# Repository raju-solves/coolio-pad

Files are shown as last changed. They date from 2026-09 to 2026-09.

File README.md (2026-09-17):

## live ysws finale

### coolio pad

A compact custom hackpad with 15 mechanical keys and a rotary encoder..
designed for quick shortcuts and smooth control. 
It also includes two LED lights 
The clean layout makes it easy to use for everyday tasks.

Each key is programmed to Do a specific shortcut command on the computer.
The rotary encoder can be used for actions like adjusting volume.
The LEDs show status or activity








## Bill of Materials (BOM)

| Name | Description | Quantity | Price (USD) | Link |
|---|---|---:|---:|---|
| XIAO RP2040 | Seeed Studio XIAO RP2040 microcontroller | 1 | 21$ | [Amazon.in](https://www.amazon.in/dp/B0DRNTQ338) |
| MX Mechanical Switches | MX-compatible mechanical keyboard switches | 15 | ~$3.96 / pack | [Amazon.in](https://www.amazon.in/dp/B0FPR2ML31) |
| 1N4148 Diodes | General-purpose switching diodes for keyboard matrix | 16 | $2.80 | [Amazon.in](https://www.amazon.in/s?k=1N4148+diode+100+pcs) |
| Rotary Encoder | EC11 rotary encoder with push-button switch | 1 | ~$1.80–$2.81 | [Amazon.in](https://www.amazon.in/s?k=EC11+rotary+encoder+5+pin+with+switch) |
| Screws | M2 / M2.5 screws for assembling the case | 4 | $3.95 | [Amazon.in](https://www.amazon.in/s?k=M2+M2.5+screws) |

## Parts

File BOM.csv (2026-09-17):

Name | Description | Quantity | Price (USD) | Link
XIAO RP2040 | Seeed Studio XIAO RP2040 microcontroller | 1 | Check listing | https://www.amazon.in/dp/B0DRNTQ338
MX Mechanical Switches | MX-compatible mechanical keyboard switches | 15 | ~3.96 / pack | https://www.amazon.in/dp/B0FPR2ML31
1N4148 Diodes | General-purpose switching diodes for keyboard matrix | 16 | Check listing | https://www.amazon.in/s?k=1N4148+diode+100+pcs
Rotary Encoder | EC11 rotary encoder with push-button switch | 1 | ~1.80-2.81 | https://www.amazon.in/s?k=EC11+rotary+encoder+5+pin+with+switch
Screws | M2 / M2.5 screws for assembling the case | 4 | Check listing | https://www.amazon.in/s?k=M2+M2.5+screws

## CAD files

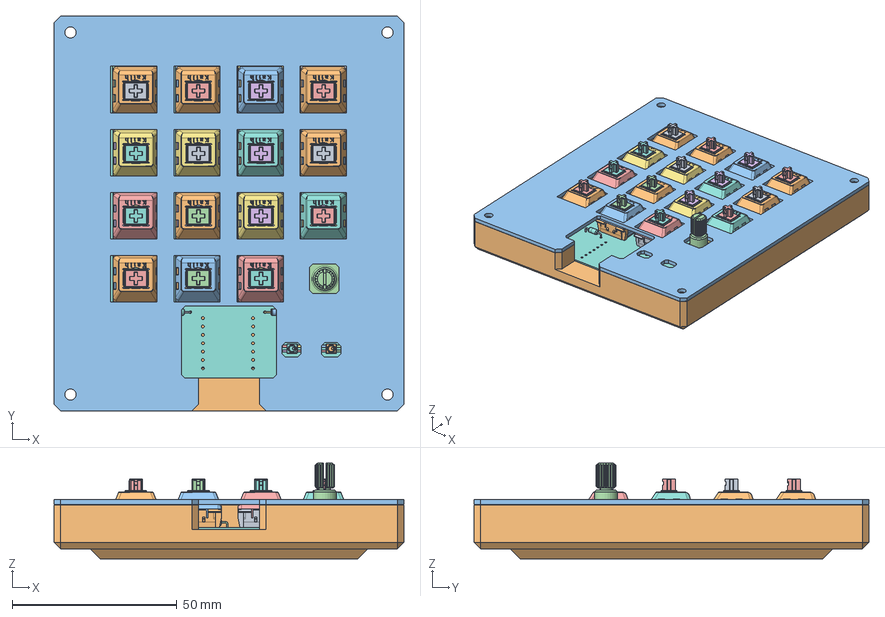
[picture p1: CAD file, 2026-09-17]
CAD/SOURCE FILE ASSEMBLY.FCStd
106.3 x 120.0 x 29.1 mm
LED_SK6812MINI-E
LED_SK6812MINI-E001
D_DO-35_SOD27_P7.62mm_Horizontal
LED_SK6812MINI-E002
D_DO-35_SOD27_P7.62mm_Horizontal001
D_DO-35_SOD27_P7.62mm_Horizontal002
D_DO-35_SOD27_P7.62mm_Horizontal003
D_DO-35_SOD27_P7.62mm_Horizontal004
D_DO-35_SOD27_P7.62mm_Horizontal005
D_DO-35_SOD27_P7.62mm_Horizontal006
D_DO-35_SOD27_P7.62mm_Horizontal007
D_DO-35_SOD27_P7.62mm_Horizontal008
D_DO-35_SOD27_P7.62mm_Horizontal009
D_DO-35_SOD27_P7.62mm_Horizontal010
D_DO-35_SOD27_P7.62mm_Horizontal011
D_DO-35_SOD27_P7.62mm_Horizontal012
D_DO-35_SOD27_P7.62mm_Horizontal013
LED_SK6812MINI-E003
Hackpad 1.1.1
Hackpad 1.1.002
Hackpad 1.1.003
Hackpad 1.1.004
Hackpad 1.1.005
D_DO-35_SOD27_P7.62mm_Horizontal014
D_DO-35_SOD27_P7.62mm_Horizontal015
D_DO-35_SOD27_P7.62mm_Horizontal016
D_DO-35_SOD27_P7.62mm_Horizontal017
D_DO-35_SOD27_P7.62mm_Horizontal018
LED_SK6812MINI-E004
D_DO-35_SOD27_P7.62mm_Horizontal019
LED_SK6812MINI-E005
D_DO-35_SOD27_P7.62mm_Horizontal020
D_DO-35_SOD27_P7.62mm_Horizontal021
D_DO-35_SOD27_P7.62mm_Horizontal022
Hackpad 1.1.006
Hackpad 1.1.007
Hackpad 1.1.008
Hackpad 1.1.009
Hackpad 1.1.010
Hackpad 1.1.011
Hackpad 1.1.012
Hackpad 1.1.013
Hackpad 1.1.014
Hackpad 1.1.015
Hackpad 1.1.016
Hackpad 1.1.017
Hackpad 1.1.018
Hackpad 1.1.019
Hackpad 1.1.020
Hackpad 1.1.021
Hackpad 1.1.022
Hackpad 1.1.023
Hackpad 1.1.024
Hackpad 1.1.025
D_DO-35_SOD27_P7.62mm_Horizontal023
LED_SK6812MINI-E006
LED_SK6812MINI-E007
LED_SK6812MINI-E008
D_DO-35_SOD27_P7.62mm_Horizontal024
D_DO-35_SOD27_P7.62mm_Horizontal025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

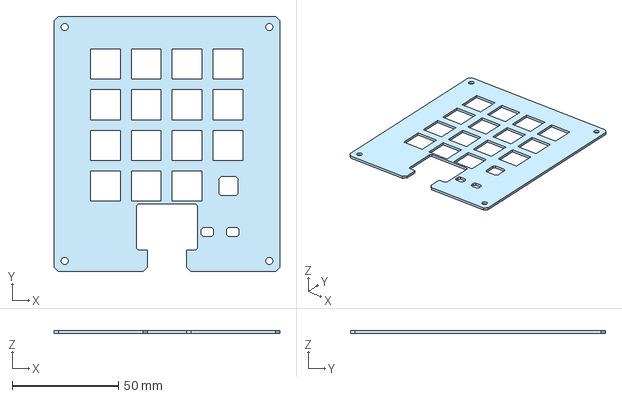
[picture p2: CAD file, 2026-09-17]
CAD/coolio top.step
106.3 x 120.0 x 1.50 mm

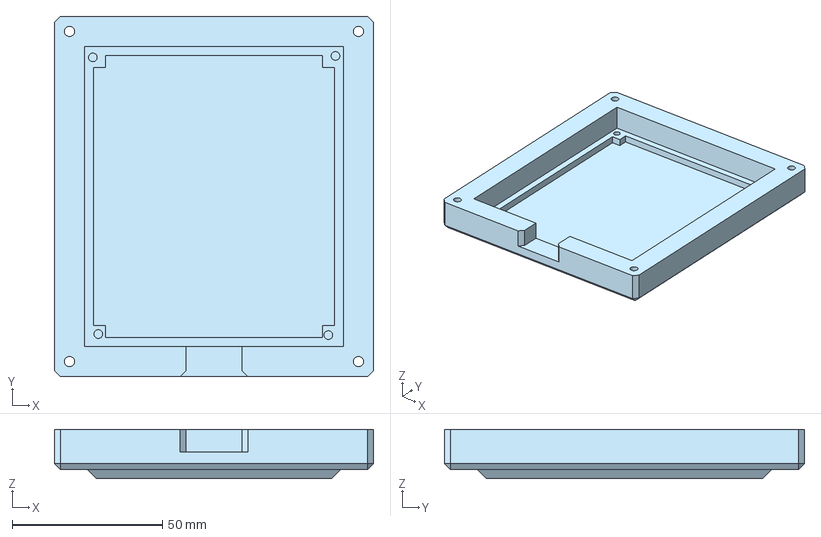
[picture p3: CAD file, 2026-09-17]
CAD/coolio bottom.step
106.3 x 120.0 x 16.4 mm

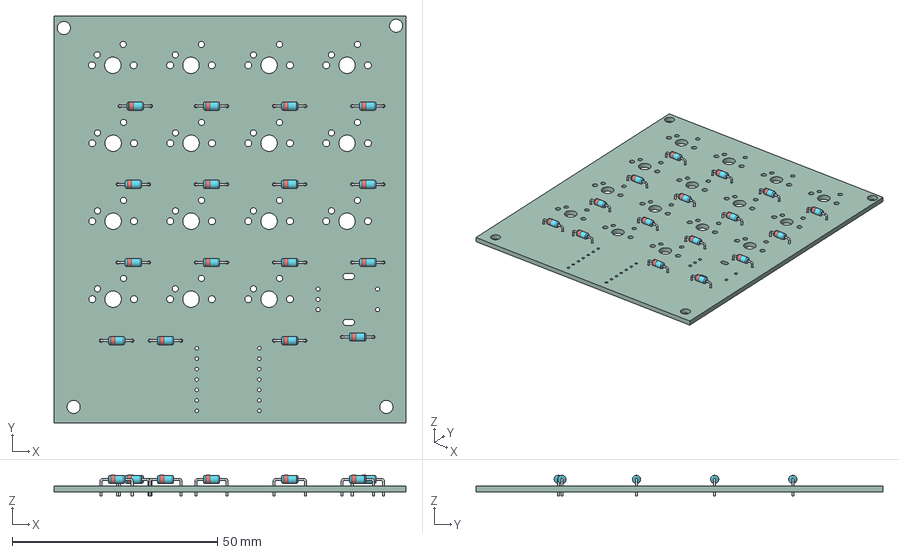
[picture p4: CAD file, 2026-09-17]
CAD/coolio pcb.step
85.7 x 99.2 x 5.01 mm
D_DO-35_SOD27_P7.62mm_Horizontal x 16
mini keyboard_PCB

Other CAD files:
CAD/ASSEMBLY.step

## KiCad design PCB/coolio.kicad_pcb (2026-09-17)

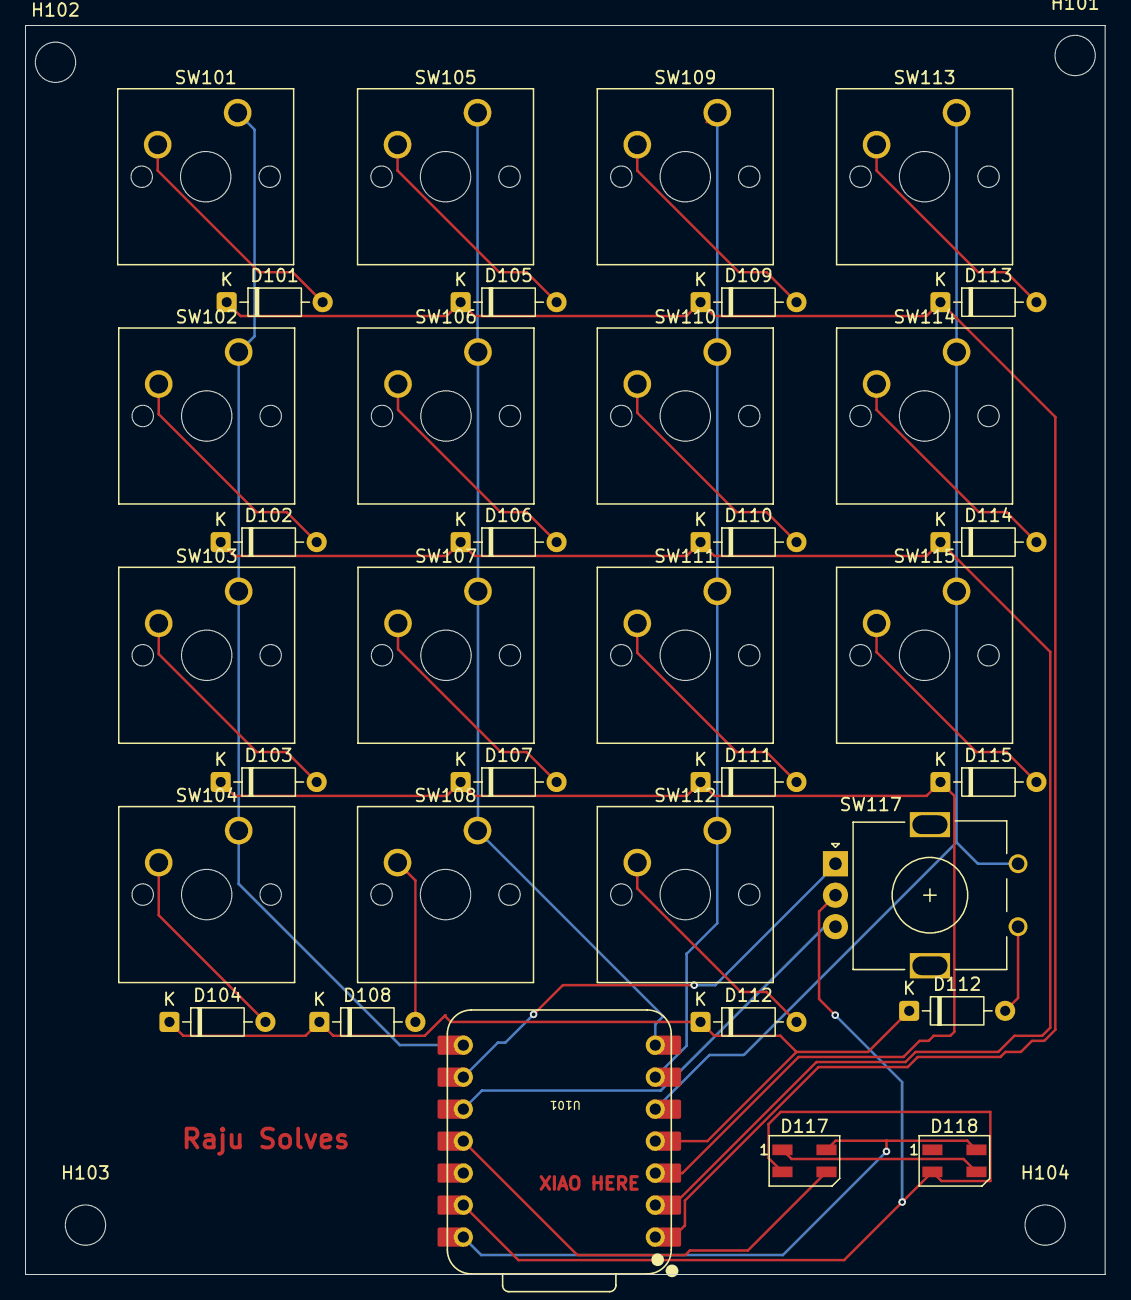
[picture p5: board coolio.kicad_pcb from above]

Board: 2 copper layers, 85.7 x 99.2 mm, 39 parts (0 on the bottom side), 29 nets.

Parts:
D101, D102, D103, D104, D105, D106, D107, D108, D109, D110, D111, D112, D112#2, D113, D114, D115: 1N4148; D_DO-35_SOD27_P7.62mm_Horizontal
D117, D118: SK6812MINI; LED_SK6812MINI_PLCC4_3.5x3.5mm_P1.75mm
H101, H102, H103, H104: MountingHole; MountingHole_3.2mm_M3
SW101, SW102, SW103, SW104, SW105, SW106, SW107, SW108, SW109, SW110, SW111, SW112, SW113, SW114, SW115: SW_Push; SW_Cherry_MX_1.00u_PCB
SW117: RotaryEncoder; RotaryEncoder_Alps_EC11E_Vertical_H20mm
U101: XIAO-RP2040-DIP

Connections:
+5V: D117.4 (VDD), D118.4 (VDD), U101.14 (VBUS)
GND: D117.2 (VSS), D118.2 (VSS), SW117.C, U101.13 (GND)
unnamed: D101.2 (A), SW101.2
unnamed: D101.1 (K), D105.1 (K), D109.1 (K), D113.1 (K), U101.1 (GPIO26/ADC0/A0)
unnamed: D102.2 (A), SW102.2
unnamed: D102.1 (K), D106.1 (K), D110.1 (K), D114.1 (K), U101.2 (GPIO27/ADC1/A1)
unnamed: D103.2 (A), SW103.2
unnamed: D103.1 (K), D107.1 (K), D111.1 (K), D115.1 (K), U101.3 (GPIO28/ADC2/A2)
unnamed: D104.2 (A), SW104.2
unnamed: D104.1 (K), D108.1 (K), D112.1 (K), D112#2.1 (K), U101.4 (GPIO29/ADC3/A3)
unnamed: D105.2 (A), SW105.2
unnamed: D106.2 (A), SW106.2
unnamed: D107.2 (A), SW107.2
unnamed: D108.2 (A), SW108.2
unnamed: D109.2 (A), SW109.2
unnamed: D110.2 (A), SW110.2
unnamed: D111.2 (A), SW111.2
unnamed: D112#2.2 (A), SW112.2
unnamed: D113.2 (A), SW113.2
unnamed: D114.2 (A), SW114.2
unnamed: D115.2 (A), SW115.2
unnamed: D117.3 (DIN), U101.11 (GPIO3/MOSI)
unnamed: D117.1 (DOUT), D118.3 (DIN)
unnamed: SW105.1, SW106.1, SW107.1, SW108.1, U101.7 (GPIO0/TX)
unnamed: SW101.1, SW102.1, SW103.1, SW104.1, U101.8 (GPIO1/RX)
unnamed: SW117.A, U101.9 (GPIO2/SCK)
unnamed: SW117.B, U101.10 (GPIO4/MISO)
unnamed: SW113.1, SW114.1, SW115.1, U101.5 (GPIO6/SDA)
unnamed: SW109.1, SW110.1, SW111.1, SW112.1, U101.6 (GPIO7/SCL)

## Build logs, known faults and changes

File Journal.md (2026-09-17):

## Time Spent

| Journal | Work | Time Spent |
|---|---|---:|
| Journal 1 | Planning and Designing | 1 hour |
| Journal 2 | Creating the Schematic in KiCad | 2.5 hours |
| Journal 3 | PCB Component Placement and Layout | 2.5 hours |
| Journal 4 | PCB Routing and Finalizing the Board | 3 hours |
| Journal 5 | Designing the Case and CAD Assembly | 3 hours |
| Journal 6 | Writing Firmware and Finishing the Project | 2 hours |
| **Total** | **Complete Coolio Pad Project** | **14 hours** |

# Coolio Pad :  Build Journal

## Journal 1 – Planning and Designing the Coolio Pad ( ## 11 SEP 2026 )

Today I started planning my hackpad project, which I decided to call Coolio Pad
I wanted to make something small and useful that I could keep next to my main keyboard.

My idea was to make a 15 key macropad with a rotary encoder.... 
The keys can be used for shortcuts like opening apps, copy andpaste, media controls, and other commands.
I also wanted the rotary encoder mainly for volume control.

For the controller, 
I decided to use the XIAO RP2040 because it is small and has enough pins for this project. 

I roughly planned the key layout first and tried to keep everything compact and clean.

After deciding the main components and layout, I was ready to start working on the schematic in KiCad.

**Time spent: 1 hour**

---

## Journal 2 – Creating the Schematic in KiCad  ( ## 12 SEP 2026 )

Today I started making the schematic for Coolio Pad in KiCad
I added the XIAO RP2040, 15 MX switches, diodes, the rotary encoder, and the other connections needed for the board.

The main thing I worked on was connecting the switches properly in a matrix. 
I used diodes with the switches so that multiple key presses can be detected correctly without unwanted inputs.

I also connected the rotary encoder to the controller and checked the power and ground connections. 
At first the schematic looked a little messy, so I rearranged the symbols and labels to make it easier to understand.

After checking the connections again, I assigned the required footprints and got the schematic ready for PCB design.

**Time spent: 2.5 hours**

---

## Journal 3 – PCB Component Placement and Layout ( ## 13 SEP 2026 )

Today I moved from the schematic to the PCB editor in KiCad. 
The first job was placing all 15 switch footprints in a clean grid so the macropad would feel organized and easy to use.

I placed the rotary encoder near the top of the board where it would be easy to reach.
Then I positioned the XIAO RP2040 and the diodes while trying to keep enough space between all the components.

A lot of the time went into moving things by small amounts and checking the spacing. 
I also thought about where the USB port would be so that the case would not block the cable.

Once the main layout looked right, I adjusted the board outline and prepared everything for routing.

**Time spent: 2.5 hours**

---

## Journal 4 – PCB Routing and Finalizing the Board ( ## 14 SEP 2026 )

Today I worked on routing the Coolio Pad PCB.
This part took more time because every switch, diode, encoder pin, and controller pin had to be connected without making the board too messy.

I routed the traces between the key matrix and the XIAO RP2040 first.
Some traces crossed each other... so I had to move components and use both PCB layers to make the routing cleaner.

After finishing the main connections... I checked the board for unconnected nets and spacing problems.
I also cleaned up some traces that had awkward turns and made the board easier to manufacture.

Finally, I checked the board outline and generated the final PCB files so the board would be ready for fabrication.

**Time spent: 3 hours**

---

## Journal 5 – Designing the Case and CAD Assembly ( ## 15 SEP 2026 )

Today I started working on the case for Coolio Pad. 
I wanted the case to be simple and compact... 
while still giving enough room for the PCB, switches, controller, rotary encoder, and USB cable.

I designed a top and bottom part for the case and added the required openings for the keys and encoder.
I also added screw holes so both parts could be fixed together properly.

After that.. I imported the PCB model into the CAD assembly and checked whether everything lined up. 
I had to make a few small changes to the dimensions and clearances 

so that the PCB would fit without touching the walls.

Once the fit looked good, I exported the final STEP files for the top, bottom, PCB, and full assembly.

**Time spent: 3 hours** ( ## 16 SEP 2026

---

## Journal 6 – Writing the Firmware and Finishing the Project ( ## 16 SEP 2026  )

Today I worked on the firmware for Coolio Pad using **KMK**. I set up the key matrix pins and assigned shortcuts to the 15 keys so each key can perform a useful action on the computer.

I also added support for the rotary encoder so it can be used for controls like increasing and decreasing volume. After setting up the basic controls, I went through the code and checked that the pin assignments matched the PCB schematic.

Once the firmware was ready, I organized the project files into separate folders for the PCB, CAD, and firmware. I also finished the BOM and README so the project would be easier for someone else to understand and build.

This was the final stage of Coolio Pad, and at this point the design, PCB, case, and firmware were all ready.

**Time spent: 2 hours**

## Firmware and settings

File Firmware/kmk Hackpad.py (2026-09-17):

import board
from kmk.kmk_keyboard import KMKKeyboard
from kmk.keys import KC
from kmk.modules.layers import Layers
from kmk.modules.macros import Macros

# Matrix scanner import (try common name; KMK builds may expose `matrix` scanner)
try:
    from kmk.scanners import matrix
    Matrix = matrix.Matrix
except Exception:
    # Fallback import path for some KMK layouts
    try:
        from kmk.scanners.matrix import Matrix
    except Exception:
        Matrix = None

keyboard = KMKKeyboard()

# Modules
layers = Layers()
macros = Macros()
keyboard.modules.append(layers)
keyboard.modules.append(macros)

# Pin mappings (confirmed)
COL_PINS = [board.GP26, board.GP27, board.GP28, board.GP29]
ROW_PINS = [board.GP6, board.GP7, board.GP0, board.GP1]

# NeoPixel
NEOPIXEL_PIN = board.GP3
NEOPIXEL_COUNT = 2

# Encoder pins
ENC_A = board.GP4
ENC_B = board.GP2
ENC_BTN = board.GP10

# Configure matrix scanner if available
if Matrix:
    keyboard.matrix = Matrix(
        row_pins=ROW_PINS,
        col_pins=COL_PINS,
        diode_orientation=matrix.DiodeOrientation.COL2ROW,
    )
else:
    # If Matrix scanner isn't available in this KMK build, try the legacy attributes
    keyboard.col_pins = COL_PINS
    keyboard.row_pins = ROW_PINS

# Example keymap: two layers (layer 0 and layer 1). Must match 4x4 matrix size (16).
# We'll leave one position as KC.NO (unused). Keys are laid out row-major.
keyboard.keymap = [
    # Layer 0: Function keys (F1-F12, etc.)
    [
        KC.ESC, KC.F1, KC.F2, KC.F3,
        KC.F4,  KC.F5, KC.F6, KC.F7,
        KC.F8,  KC.F9, KC.F10, KC.F11,
        KC.F12, KC.PSCREEN, KC.INSERT, KC.NO,
    ],
    # Layer 1: Numbers and symbols
    [
        KC.GRAVE, KC.ONE, KC.TWO, KC.THREE,
        KC.FOUR, KC.FIVE, KC.SIX, KC.SEVEN,
        KC.EIGHT, KC.NINE, KC.ZERO, KC.MINUS,
        KC.EQUAL, KC.BACKSPACE, KC.TAB, KC.NO,
    ],
]

# NeoPixel initialization (attempt to import `neopixel`)
pixels = None
BASE_COLOR = (0, 16, 0)  # Green base color

try:
    import neopixel
    pixels = neopixel.NeoPixel(NEOPIXEL_PIN, NEOPIXEL_COUNT, brightness=0.2, auto_write=True)
    pixels.fill(BASE_COLOR)
except Exception:
    pixels = None

# Volume tracking (local state). We keep an internal level so we can map it
# to NeoPixel brightness. The encoder will still send HID volume up/down
# via `enc.keymap` below; we rely on the encoder module to send those keys.
VOLUME_LEVEL = 5
MAX_VOLUME_LEVEL = 10

def _set_pixels_by_volume(level):
    """Scale the BASE_COLOR by level/MAX_VOLUME_LEVEL and write to pixels."""
    if pixels is None:
        return
    level = max(0, min(MAX_VOLUME_LEVEL, level))
    scale = level / float(MAX_VOLUME_LEVEL) if MAX_VOLUME_LEVEL else 0
    r, g, b = BASE_COLOR
    pixels.fill((int(r * scale), int(g * scale), int(b * scale)))

# Layer change blink feedback
def _blink_pixels_for_layer(layer_num):
    """Blink LEDs to indicate layer change. Layer 0: 1 blink, Layer 1: 2 blinks."""
    if pixels is None:
        return
    try:
        import time
        blink_count = 1 if layer_num == 0 else 2
        for _ in range(blink_count):
            pixels.fill((255, 255, 255))  # White blink
            time.sleep(0.15)
            # Return to volume-based color
            _set_pixels_by_volume(VOLUME_LEVEL)
            time.sleep(0.1)
    except Exception:
        pass

# initialize pixel brightness according to starting volume
_set_pixels_by_volume(VOLUME_LEVEL)

# Encoder setup (optional)
try:
    from kmk.modules.encoder import Encoder

    enc = Encoder(ENC_A, ENC_B, pin_btn=ENC_BTN, value_when_pressed=False)
    # Map rotation: (ccw_action, cw_action) - this sends HID volume keys
    enc.keymap = ((KC.VOLD, KC.VOLU),)

    # Encoder callback: handles rotation and button events.
    # Rotation updates the local VOLUME_LEVEL and scales NeoPixels.
    # Button press toggles between Layer 0 and Layer 1.
    def _enc_event(evt):
        global VOLUME_LEVEL
        try:
            # rotation event (some implementations pass an int delta)
            if isinstance(evt, int) or isinstance(evt, float):
                delta = 1 if evt > 0 else -1
                VOLUME_LEVEL = max(0, min(MAX_VOLUME_LEVEL, VOLUME_LEVEL + delta))
                _set_pixels_by_volume(VOLUME_LEVEL)
                return
            # button event (pressed True/False)
            if isinstance(evt, bool):
                if evt:
                    layers.toggle(1)
                    # Determine current layer after toggle and blink feedback
                    try:
                        current_layer = layers.current_layer
                    except Exception:
                        current_layer = 0
                    _blink_pixels_for_layer(current_layer)
                return
        except Exception:
            # Fallback: ignore if callback signature differs
            return

    enc.callback = _enc_event
    keyboard.modules.append(enc)
except Exception:
    # Encoder module not available in this build — ignore for now
    pass

# Example macros: attach a simple macro to a key (optional)
# Uncomment or modify to add text-based macros
# keyboard.keymap[0][2] = KC.MACRO("Hello from Divyanshu's macropad!")

if __name__ == '__main__':
    keyboard.go()

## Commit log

2026-09-17 coolio top
    [coolio top.step]
2026-09-17 assembly of the coolio
    [ASSEMBLY.step]
2026-09-17 pcb and other files
2026-09-17 source file
    [SOURCE FILE ASSEMBLY.FCStd]
2026-09-17 gerber ( for pcb)
